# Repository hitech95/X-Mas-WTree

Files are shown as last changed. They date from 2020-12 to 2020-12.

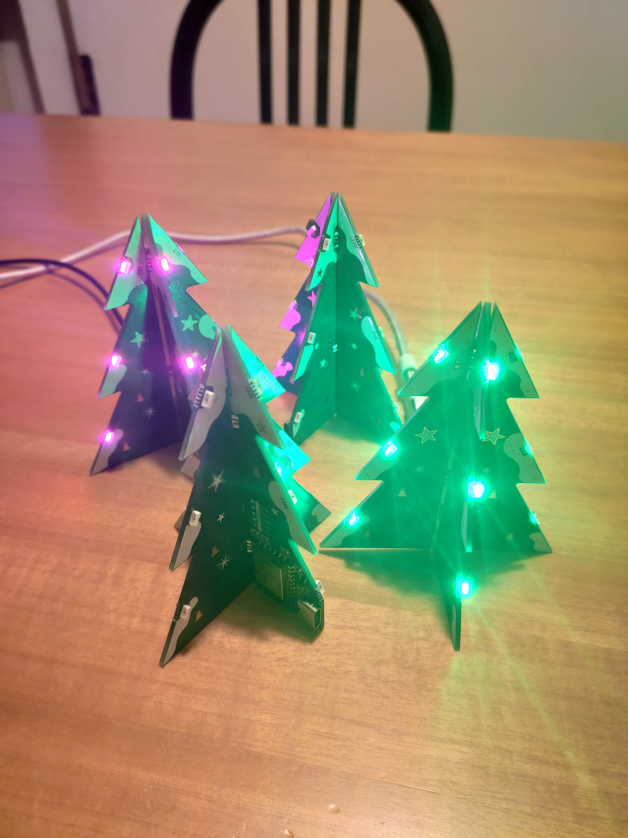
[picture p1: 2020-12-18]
3DModel/IMG_20201218_164741.jpg

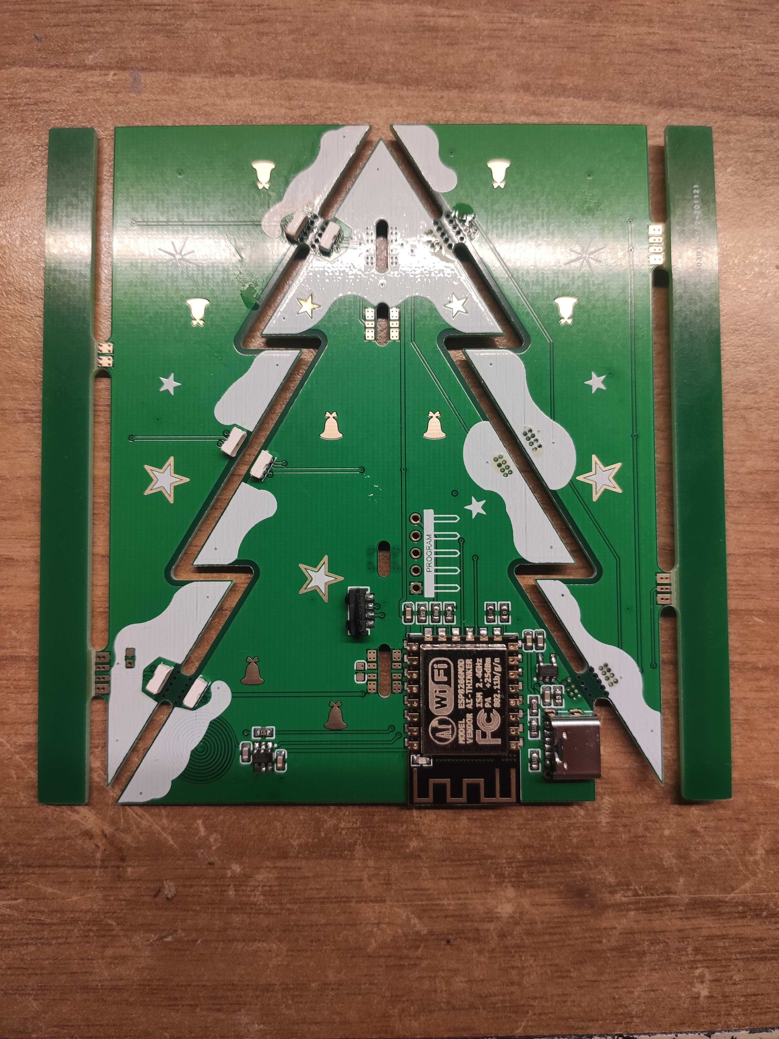
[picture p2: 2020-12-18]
3DModel/IMG_20201217_232000.jpg

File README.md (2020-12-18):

#  X-Mas-WTree!

This is a simple Chrismas tree project inspired by [bluqesh](https://www.instructables.com/PCB-Christms-Tree/). I've updated its design adding slots for board to board connection and addressable RGB leds.

At that point I've also switched the MCU to an ESP8266 to add WiFi capability, and using the amazing [WLED](https://github.com/Aircoookie/WLED) project to control everything.

Project files are available in the `Project Outputs for xMas-Tree` directory.
In the 3DModel folder there is the 3D model and the "textures", and some photos.

### Features

 - USB C Compatible, it negotiate 5V@900mA
 - IR Remote receiver
 - WiFI controllable
 - Full PCB is 10cm x 10cm so it fit the 2$ [JLCPCB](https://jlcpcb.com/) option.
 - Most of the components are available from LCSC.**\***
 - Different patterns and animations
 - More info on [WLED](https://github.com/Aircoookie/WLED) project

**\*The ESP8266-12 and the LEDs have to be bought separately**

## Soldering

While placing the `0603` components is not that hard if you have SMD skills soldering the LEDs is quite **difficult!** Mostly due to the VIAs to give the pads more rigidity. I'm still experimenting a way to easily solder the LEDs, probably using a stencil and low temp solder with hot air is the best solution.

Right now I'm soldering the second tree.

For now my assembly procedure (without hot plate soldering and solder paste) is:

 1. Solder all the `0603` excpet the one near the USB C contacts.
 2. Solder the USB C
 3. Solder the 5.1K resistor skipped on step 1.
 4. Solder the ICs.
 5. Solder the LEDs, make sure that they are firmly soldered.
 6. Solder the ESP module.
 7. Check for shorts and program the ESP. Test if first 6 leds are working.
 8. Snap the boards and solder them together
 9. Check again for shorts and enjoy!

Probably with hot air and a low melting point solder paste step 1-6 can be done in a single jump. 
Right now I only have flux, and 60/40 solder.

I managed to find a old solder paste, and yes, it makes the assemply a lot easier.
I don't have a stencil and in anyu case soldering the LEDs would require manual reworks due to vias under the pads.

To solder the LEDS with this metod i proceed as:
 1. Fill the LED pads with the solder paste proceed with the reflow WITHOUT the LEDs.
 2. The solder would be wiked into the vias, apply again the solder paster and properly reflow the LEDs.
 
With my cheap hot air station I use 360°C to solder all the components and 220°C for the LEDs.

I'm a noob with LED soldering I've melted 8 of them on assempling 4 tree. So be careful.
(Four on the first board, one fell on the fold and was lost. One had RED color not working. The others 2 has been melted on second and third board)

## PCB Errors
 - The USB FUSE seems to be not working as expected, so a 0OHM link is
   required. (This seems to be a single case)
 - The LEDS PADs have vias to give them more strength, but unfortunatly makes a lot harder to solder the LEDs
 - Some 4.7uF caps (LEDs bypass seems to be not needed and some of those cant be soldered or the boards cannot be assempled in shape)

## PROGRAMMING

The touch button is connected to the `BOOT0` pin, so you have to press that while you start the sketch upload process.
A FTDI 3.3V module with `RESET` is required, I didnt had one so I temporary connected a wire to ground while also pressing the TOUCH button.

The FW can be found under the [WLED](https://github.com/Aircoookie/WLED/releases) repository, I'm using a ESP12, so `d1_mini` is the right platform to choose.

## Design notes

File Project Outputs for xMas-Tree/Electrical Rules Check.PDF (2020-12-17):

### Electrical Rules Check Report

Class | Document | Message
Warning | Main.SchDoc | Net LEDS_L has no driving source (Pin LED1-1,Pin R8-2)
Warning | Main.SchDoc | Net TOCUH_PAD has no driving source (Pin C5-2,Pin U3-3)
venerdì 20 nov 2020 3:37:14 PM | Page 1 of 1

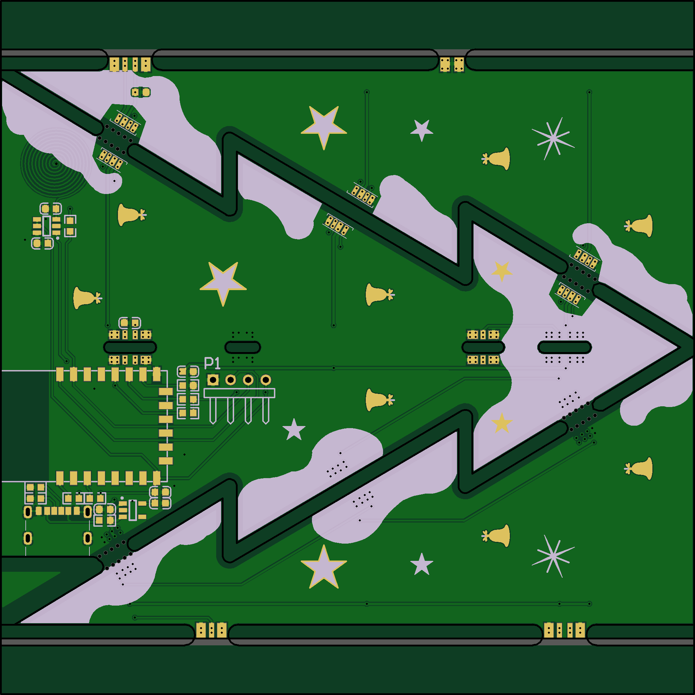
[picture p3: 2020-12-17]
3DModel/top.png

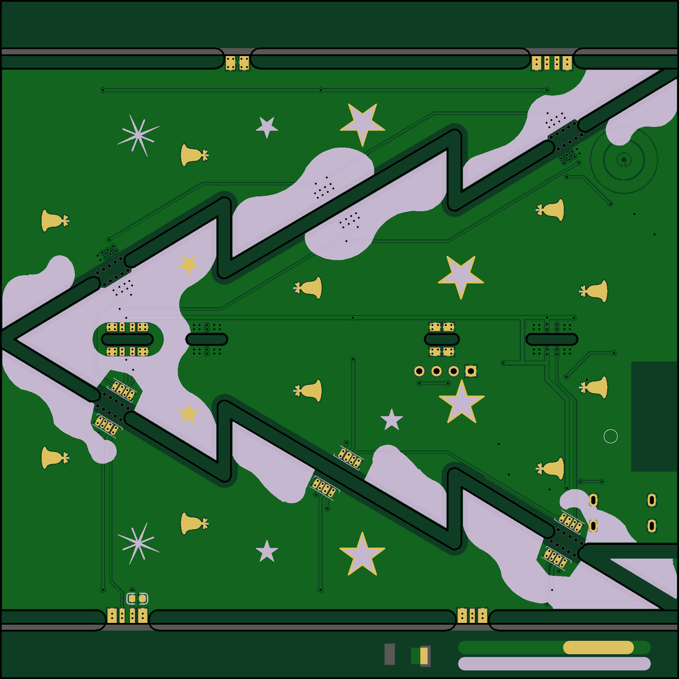
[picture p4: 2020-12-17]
3DModel/bottom.png

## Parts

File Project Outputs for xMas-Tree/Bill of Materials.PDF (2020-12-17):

Comment | Description | Designator | Quantity | Supplier | SuppliersPartNum ber | Manufacturer | PartNumber
10uF | Chip capacitors | C1, C2 | 2 | LC | C19702 | Samsung Electro-Mechanics | CL10A106KP8NN NC
100nF | Chip capacitors | C3, C4 | 2 | LC | C14663 | YAGEO | CC0603KRX7R9B B104
30pF | Chip capacitors | C5 | 1 | LC | C22397 | Samsung Electro-Mechanics | CL10C300JB8NNN C
4.7uF | Chip capacitors | C6, C7, C8, C9 | 4 | LC | C19666 | Samsung Electro-Mechanics | CL10A475KO8NN NC
JK-SMD0603-035 | PTC Resettable Fuse | F1 | 1 | LC | C369144 | Jinrui Electronic Materials Co. | JK-SMD0603-035
SK68XX SIDE | Addressable LED | LED1, LED2, LED3, LED4, LED5, LED6, LED7, LED8, LED9, LED10, LED11, LED12 | 12 | | | Shenzhen Normand Electronic Co.,Ltd | SK6812 SIDE
Header 5H | Header, 5-Pin, Right Angle | P1 | 1
5.1KΩ ±1% | Chip resistor | R1, R2 | 2 | LC | C23186 | Uniroyal Elec | 0603WAF5101T5 E
10KΩ ±1% | Chip resistor | R3, R4, R6, R7 | 4 | LC | C25804 | Uniroyal Elec | 0603WAF1002T5 E
4.7KΩ ±1% | Chip resistor | R5, R8 | 2 | LC | C23162 | Uniroyal Elec | 0603WAF4701T5 E
0Ω ±1% | Chip resistor | R9 | 1 | LC | C21189 | Uniroyal Elec | 0603WAF0000T5 E
ME6211C33 | LDO | U1 | 1 | LC | C82942 | MICRONE(Nanjin g Micro One Elec) | ME6211C33M5G-N
ESP8266-12 | | U2 | 1
TTP223 | Touch Pad Detector IC | U3 | 1 | LC | C93723 | Tontek Design Tech | TTP223N-HA6
SIRAB39R1 | Infrared remote receiver | U4 | 1 | LC | C393728 | Hangzhou Silan Microelectronics | SIRAB39R1
TYPE-C-31-M-17 | USB Connectors | USBC | 1 | LC | C283540 | Korean Hroparts Elec | TYPE-C-31-M-17

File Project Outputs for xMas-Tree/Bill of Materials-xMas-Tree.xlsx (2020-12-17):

Comment | Description | Designator | Quantity | Supplier | SuppliersPartNumber | Manufacturer | PartNumber
10uF | Chip capacitors | C1, C2 | 2 | LC | C19702 | Samsung Electro-Mechanics | CL10A106KP8NNNC
100nF | Chip capacitors | C3, C4 | 2 | LC | C14663 | YAGEO | CC0603KRX7R9BB104
30pF | Chip capacitors | C5 | 1 | LC | C22397 | Samsung Electro-Mechanics | CL10C300JB8NNNC
4.7uF | Chip capacitors | C6, C7, C8, C9 | 4 | LC | C19666 | Samsung Electro-Mechanics | CL10A475KO8NNNC
JK-SMD0603-035 | PTC Resettable Fuse | F1 | 1 | LC | C369144 | Jinrui Electronic Materials Co. | JK-SMD0603-035
SK68XX SIDE | Addressable LED | LED1, LED2, LED3, LED4, LED5, LED6, LED7, LED8, LED9, LED10, LED11, LED12 | 12 |  |  | Shenzhen Normand Electronic Co.,Ltd | SK6812 SIDE
Header 5H | Header, 5-Pin, Right Angle | P1 | 1
5.1KΩ ±1% | Chip resistor | R1, R2 | 2 | LC | C23186 | Uniroyal Elec | 0603WAF5101T5E
10KΩ ±1% | Chip resistor | R3, R4, R6, R7 | 4 | LC | C25804 | Uniroyal Elec | 0603WAF1002T5E
4.7KΩ ±1% | Chip resistor | R5, R8 | 2 | LC | C23162 | Uniroyal Elec | 0603WAF4701T5E
0Ω ±1% | Chip resistor | R9 | 1 | LC | C21189 | Uniroyal Elec | 0603WAF0000T5E
ME6211C33 | LDO | U1 | 1 | LC | C82942 | MICRONE(Nanjing Micro One Elec) | ME6211C33M5G-N
ESP8266-12 |  | U2 | 1
TTP223 | Touch Pad Detector IC | U3 | 1 | LC | C93723 | Tontek Design Tech | TTP223N-HA6
SIRAB39R1 | Infrared remote receiver | U4 | 1 | LC | C393728 | Hangzhou Silan Microelectronics | SIRAB39R1
TYPE-C-31-M-17 | USB Connectors | USBC | 1 | LC | C283540 | Korean Hroparts Elec | TYPE-C-31-M-17

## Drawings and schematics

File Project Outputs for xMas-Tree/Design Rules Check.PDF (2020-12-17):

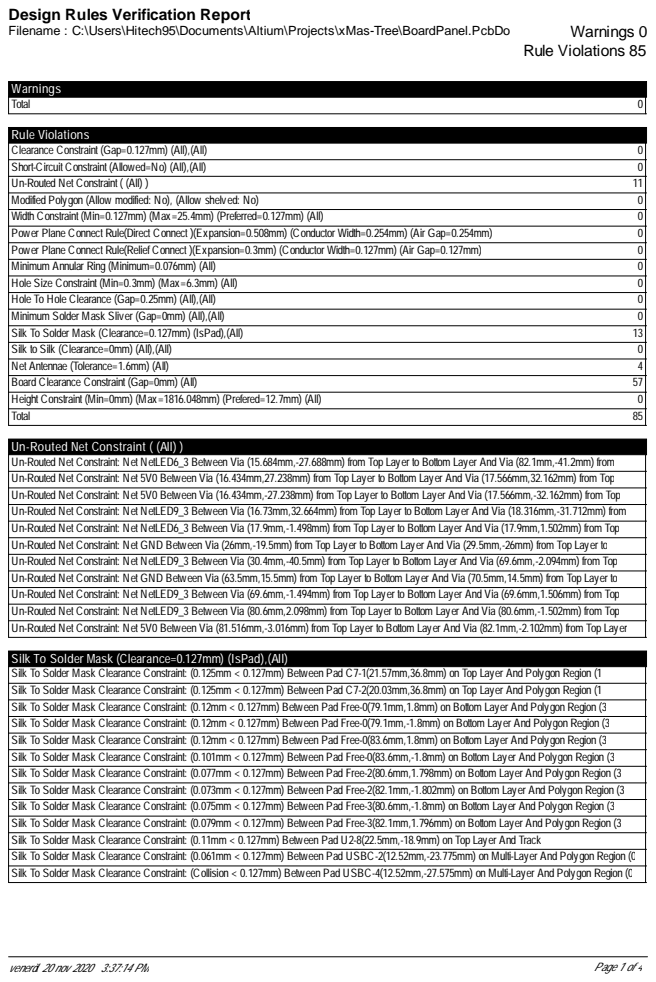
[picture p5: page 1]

Design Rules Verification Report

Un-Routed Net Constraint ( (All) )
Un-Routed Net Constraint: Net NetLED6_3 Between Via (15.684mm,-27.688mm) from Top Layer to Bottom Layer And Via (82.1mm,-41.2mm) from
Un-Routed Net Constraint: Net 5V0 Between Via (16.434mm,27.238mm) from Top Layer to Bottom Layer And Via (17.566mm,32.162mm) from Top
Un-Routed Net Constraint: Net 5V0 Between Via (16.434mm,-27.238mm) from Top Layer to Bottom Layer And Via (17.566mm,-32.162mm) from Top
Un-Routed Net Constraint: Net NetLED9_3 Between Via (16.73mm,32.664mm) from Top Layer to Bottom Layer And Via (18.316mm,-31.712mm) from
Un-Routed Net Constraint: Net NetLED6_3 Between Via (17.9mm,-1.498mm) from Top Layer to Bottom Layer And Via (17.9mm,1.502mm) from Top
Un-Routed Net Constraint: Net GND Between Via (26mm,-19.5mm) from Top Layer to Bottom Layer And Via (29.5mm,-26mm) from Top Layer to
Un-Routed Net Constraint: Net NetLED9_3 Between Via (30.4mm,-40.5mm) from Top Layer to Bottom Layer And Via (69.6mm,-2.094mm) from Top
Un-Routed Net Constraint: Net GND Between Via (63.5mm,15.5mm) from Top Layer to Bottom Layer And Via (70.5mm,14.5mm) from Top Layer to
Un-Routed Net Constraint: Net NetLED9_3 Between Via (69.6mm,-1.494mm) from Top Layer to Bottom Layer And Via (69.6mm,1.506mm) from Top
Un-Routed Net Constraint: Net NetLED9_3 Between Via (80.6mm,2.098mm) from Top Layer to Bottom Layer And Via (80.6mm,-1.502mm) from Top
Un-Routed Net Constraint: Net 5V0 Between Via (81.516mm,-3.016mm) from Top Layer to Bottom Layer And Via (82.1mm,-2.102mm) from Top Layer

Silk To Solder Mask (Clearance=0.127mm) (IsPad),(All)
Silk To Solder Mask Clearance Constraint: (0.125mm < 0.127mm) Between Pad C7-1(21.57mm,36.8mm) on Top Layer And Polygon Region (1
Silk To Solder Mask Clearance Constraint: (0.125mm < 0.127mm) Between Pad C7-2(20.03mm,36.8mm) on Top Layer And Polygon Region (1
Silk To Solder Mask Clearance Constraint: (0.12mm < 0.127mm) Between Pad Free-0(79.1mm,1.8mm) on Bottom Layer And Polygon Region (3
Silk To Solder Mask Clearance Constraint: (0.12mm < 0.127mm) Between Pad Free-0(79.1mm,-1.8mm) on Bottom Layer And Polygon Region (3
Silk To Solder Mask Clearance Constraint: (0.12mm < 0.127mm) Between Pad Free-0(83.6mm,1.8mm) on Bottom Layer And Polygon Region (3
Silk To Solder Mask Clearance Constraint: (0.101mm < 0.127mm) Between Pad Free-0(83.6mm,-1.8mm) on Bottom Layer And Polygon Region (3
Silk To Solder Mask Clearance Constraint: (0.077mm < 0.127mm) Between Pad Free-2(80.6mm,1.798mm) on Bottom Layer And Polygon Region (3
Silk To Solder Mask Clearance Constraint: (0.073mm < 0.127mm) Between Pad Free-2(82.1mm,-1.802mm) on Bottom Layer And Polygon Region (3
Silk To Solder Mask Clearance Constraint: (0.075mm < 0.127mm) Between Pad Free-3(80.6mm,-1.8mm) on Bottom Layer And Polygon Region (3
Silk To Solder Mask Clearance Constraint: (0.079mm < 0.127mm) Between Pad Free-3(82.1mm,1.796mm) on Bottom Layer And Polygon Region (3
Silk To Solder Mask Clearance Constraint: (0.11mm < 0.127mm) Between Pad U2-8(22.5mm,-18.9mm) on Top Layer And Track
Silk To Solder Mask Clearance Constraint: (0.061mm < 0.127mm) Between Pad USBC-2(12.52mm,-23.775mm) on Multi-Layer And Polygon Region (0
Silk To Solder Mask Clearance Constraint: (Collision < 0.127mm) Between Pad USBC-4(12.52mm,-27.575mm) on Multi-Layer And Polygon Region (0

Net Antennae (Tolerance=1.6mm) (All)
Net Antennae: Via (80.6mm,-1.502mm) from Top Layer to Bottom Layer Net Antennae: Via (80.6mm,-2.102mm) from Top Layer to Bottom Layer Net Antennae: Via (82.1mm,-1.502mm) from Top Layer to Bottom Layer Net Antennae: Via (82.1mm,-2.102mm) from Top Layer to Bottom Layer

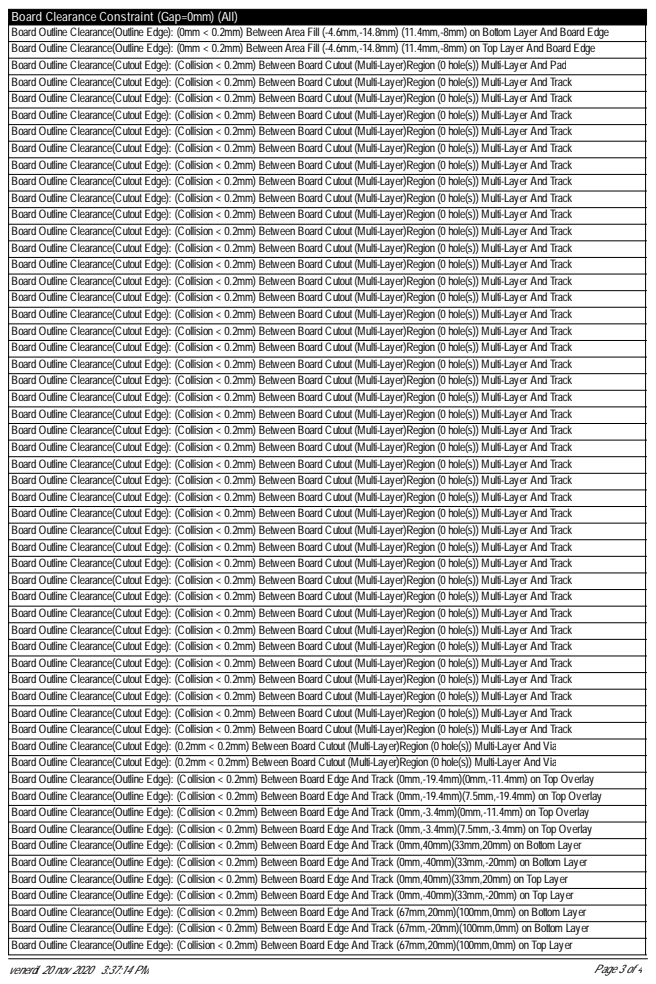
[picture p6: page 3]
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

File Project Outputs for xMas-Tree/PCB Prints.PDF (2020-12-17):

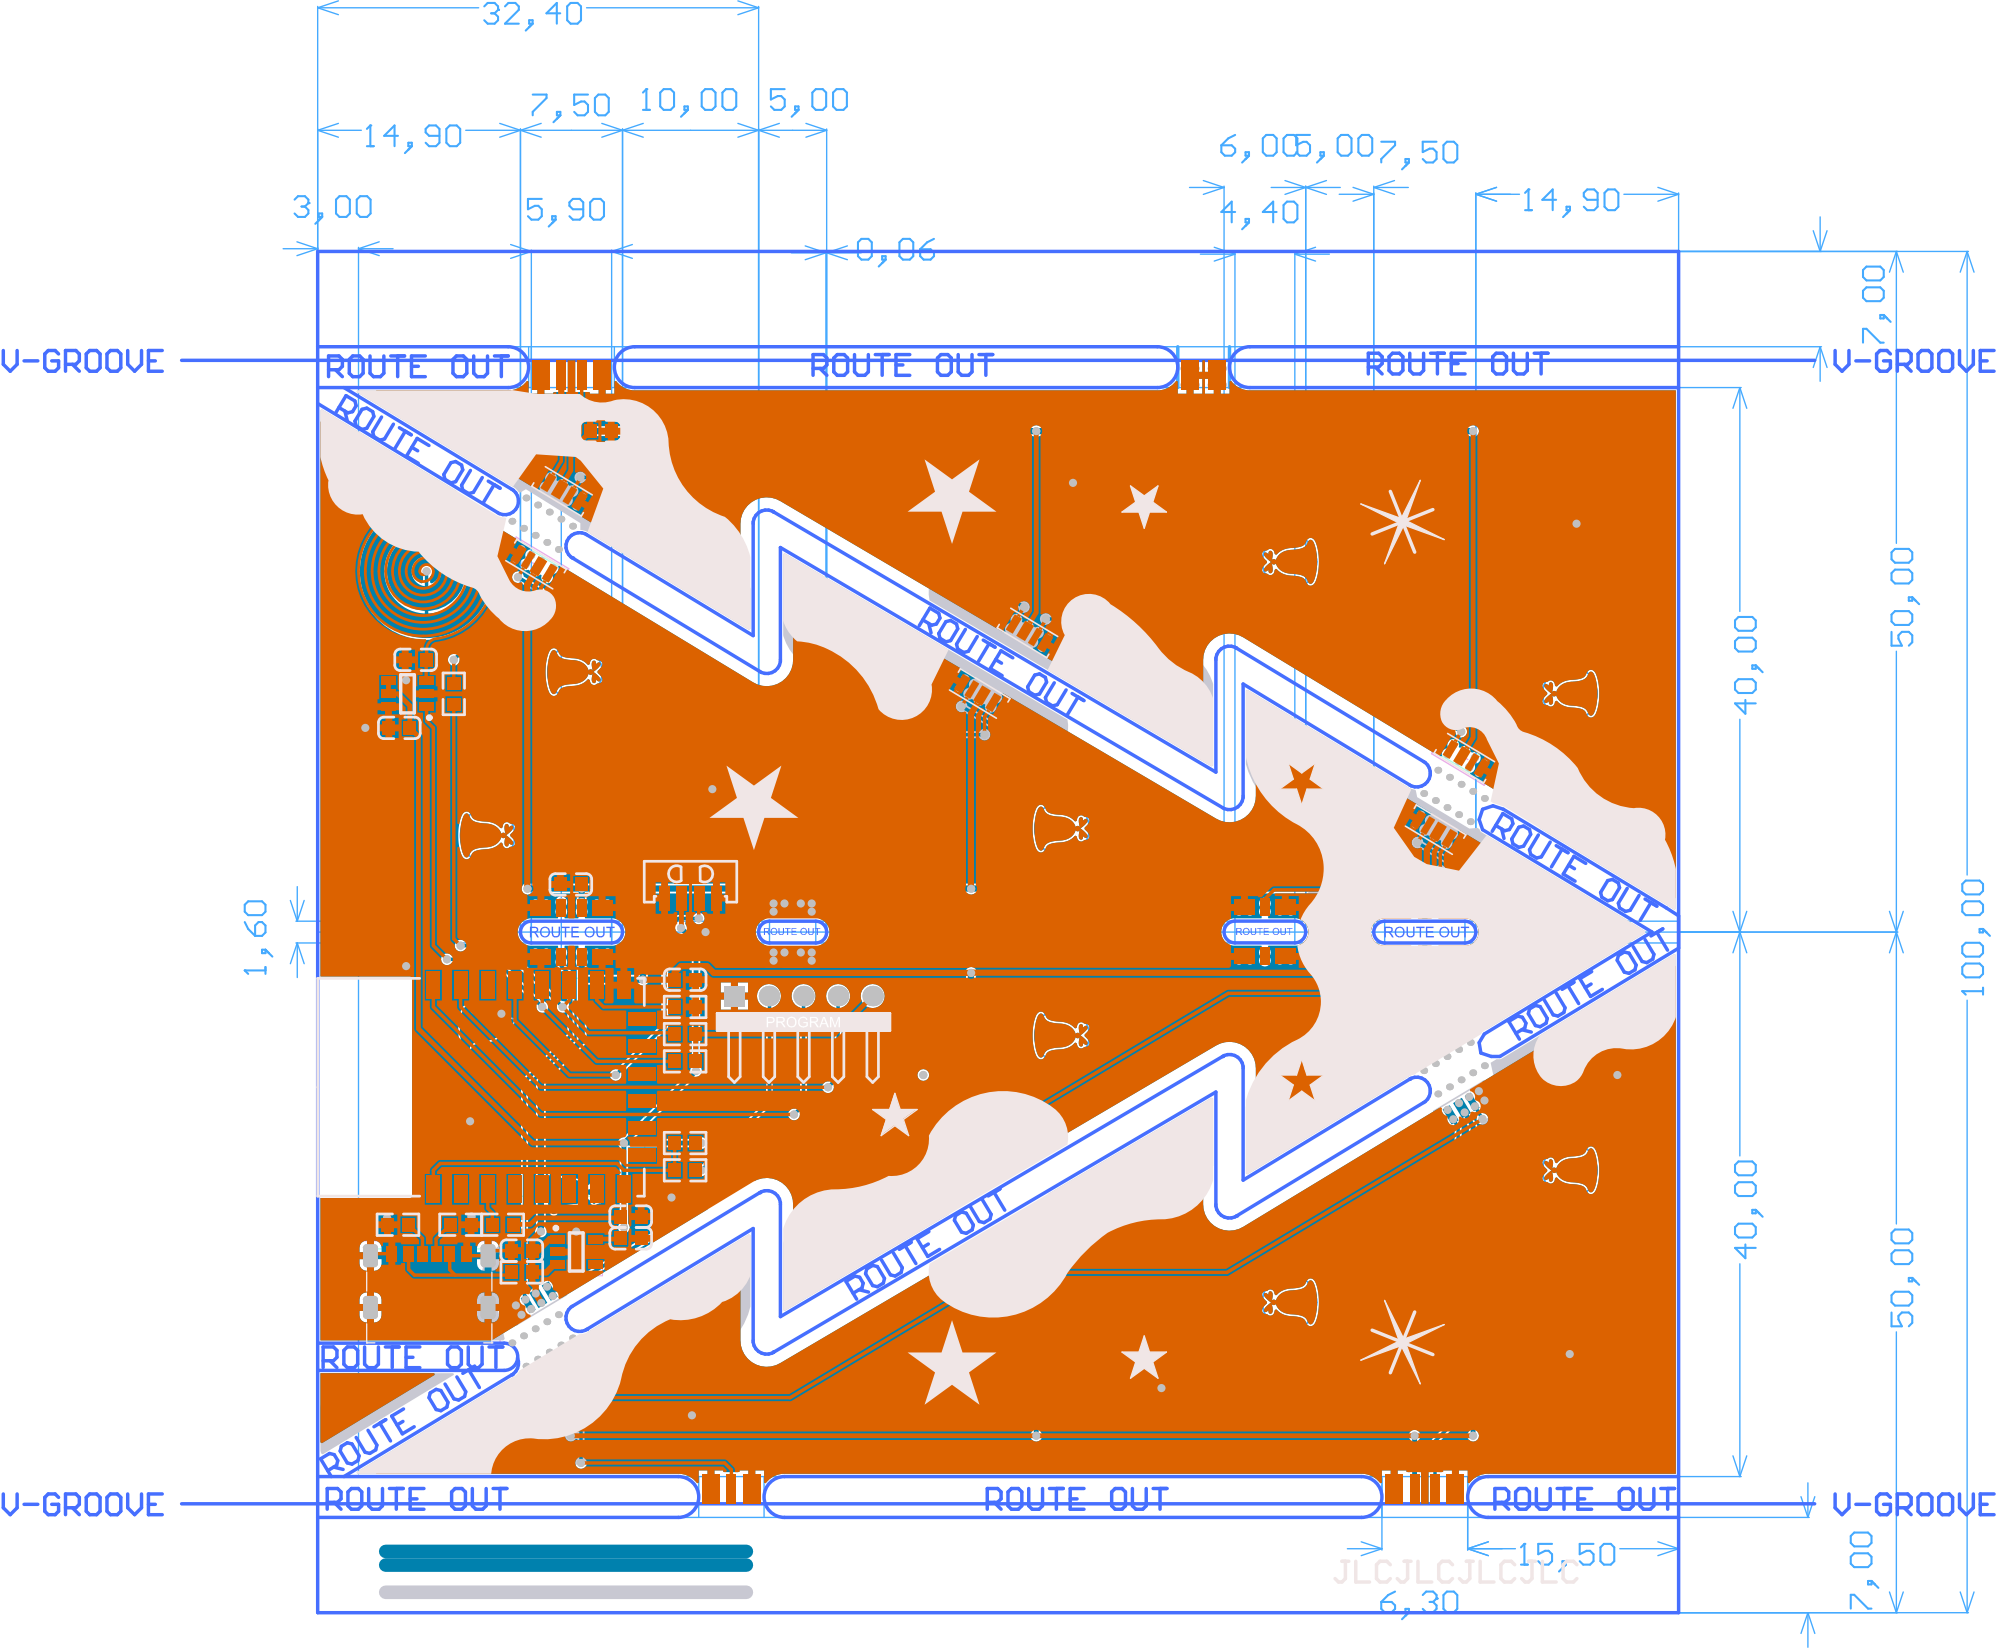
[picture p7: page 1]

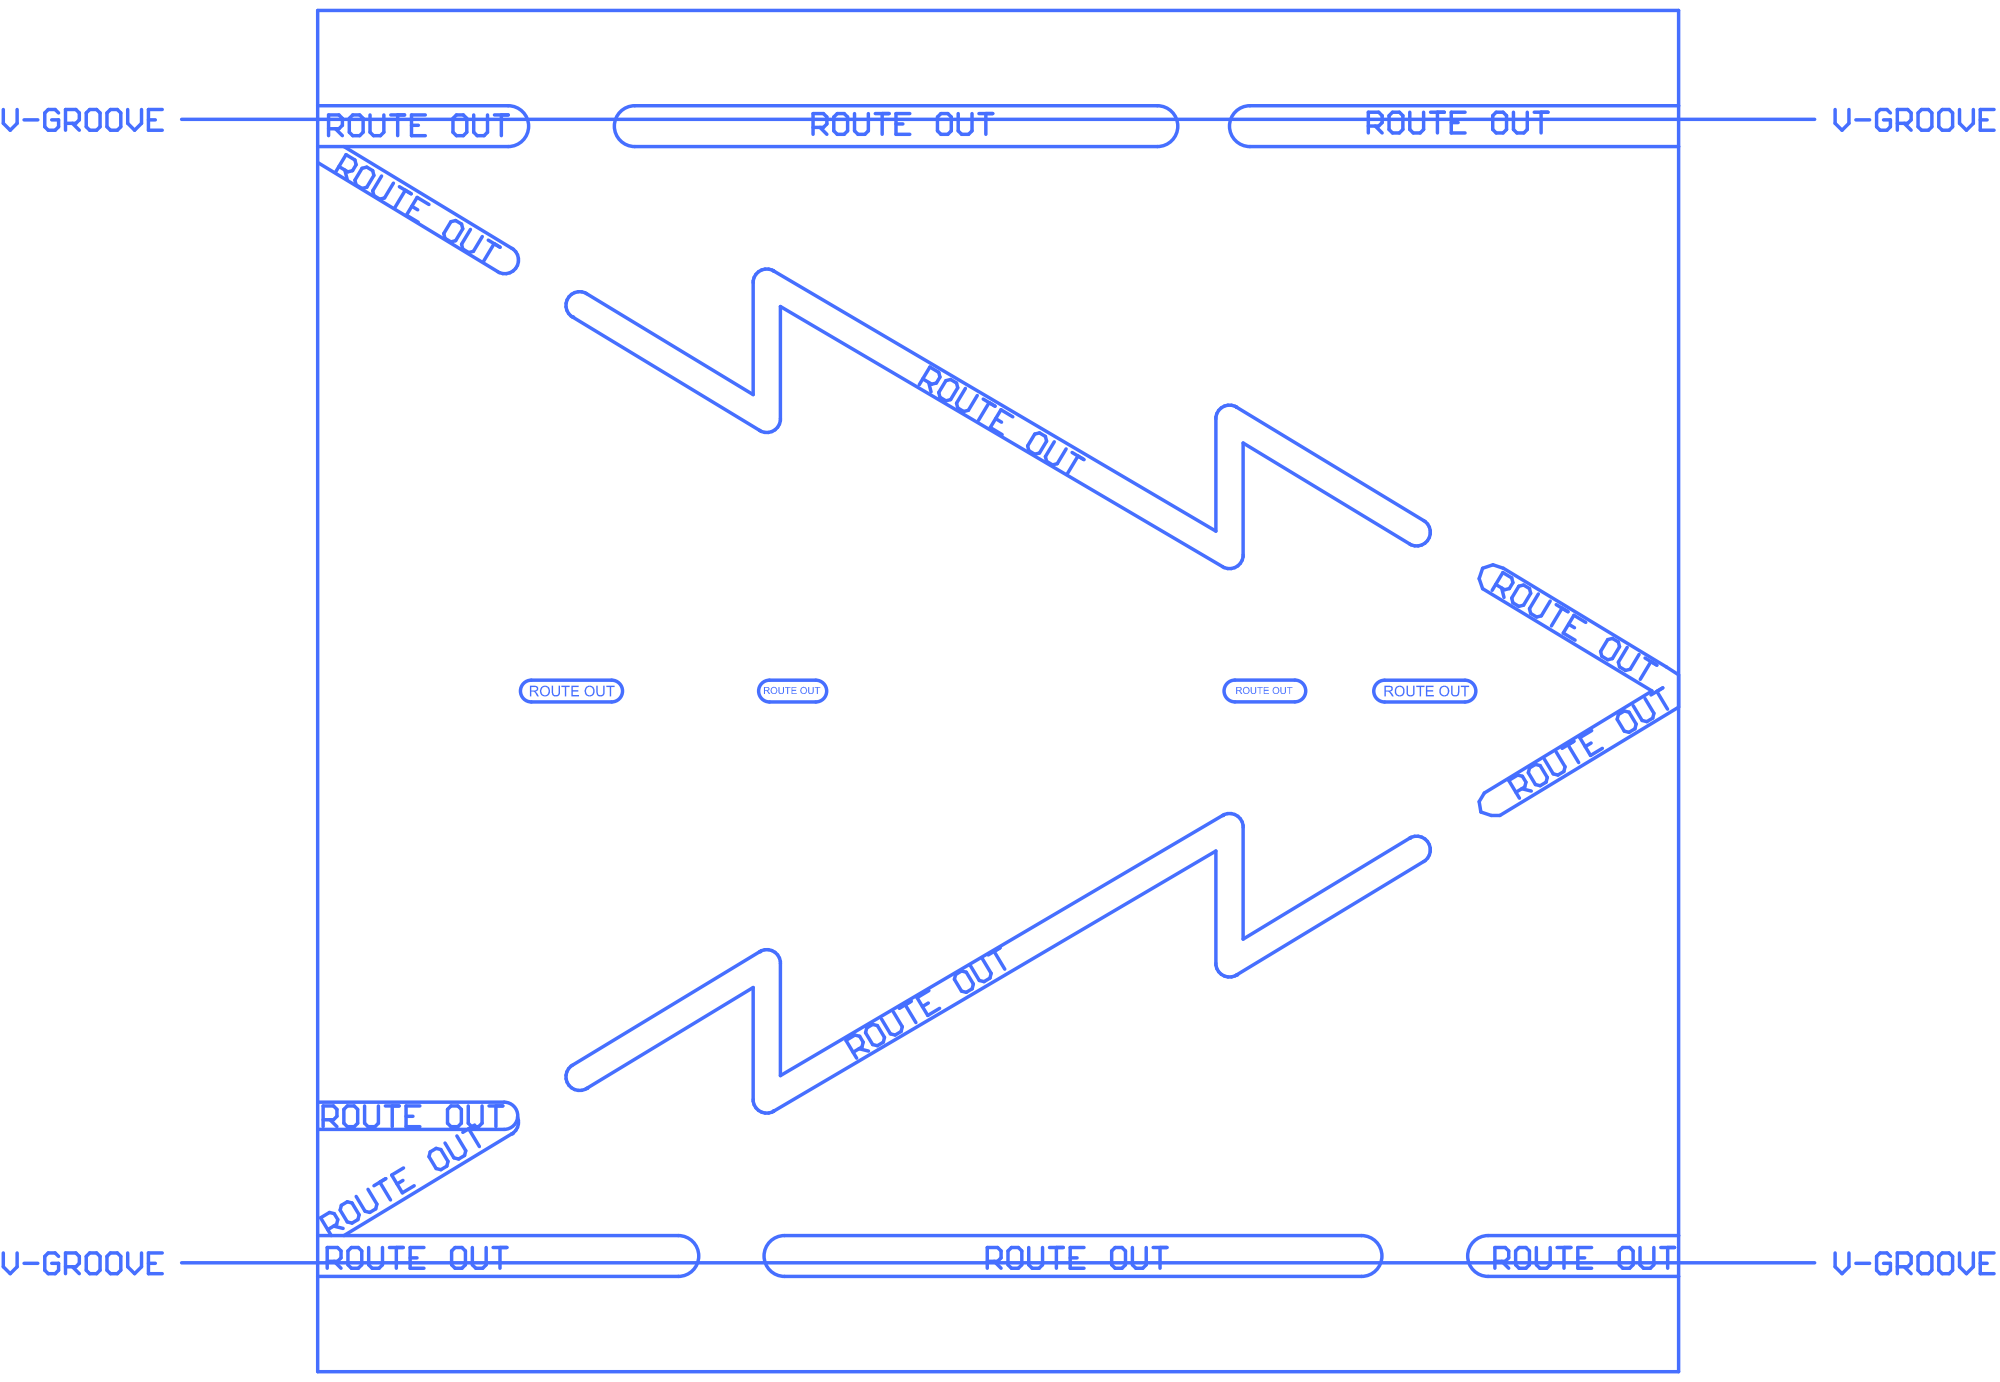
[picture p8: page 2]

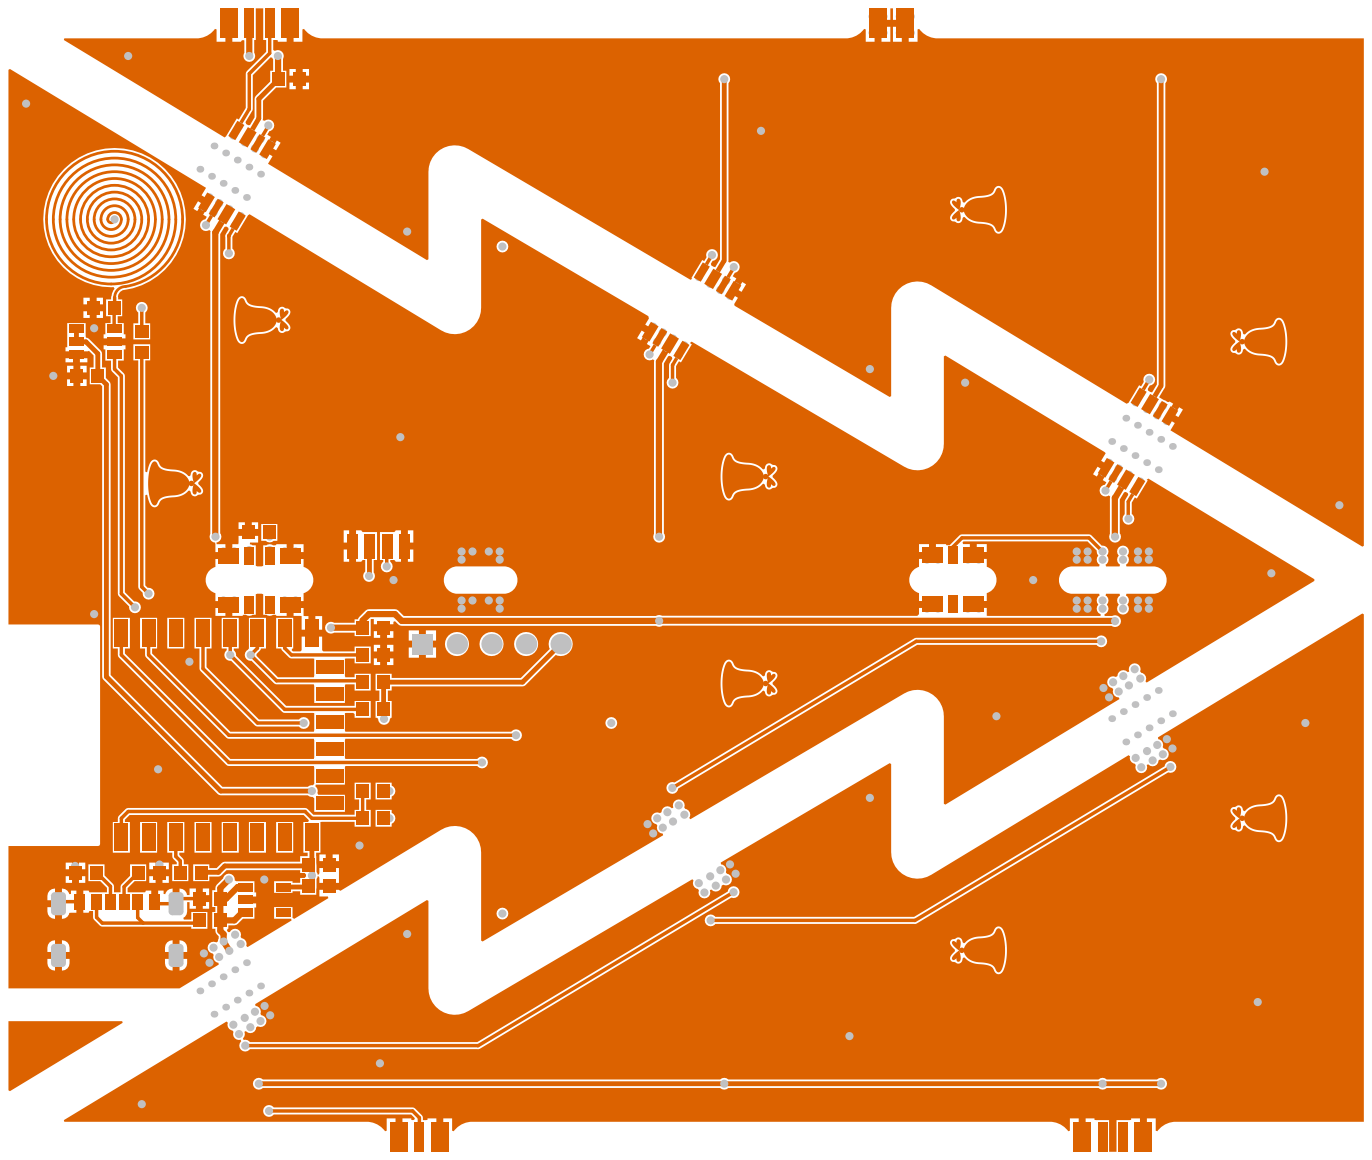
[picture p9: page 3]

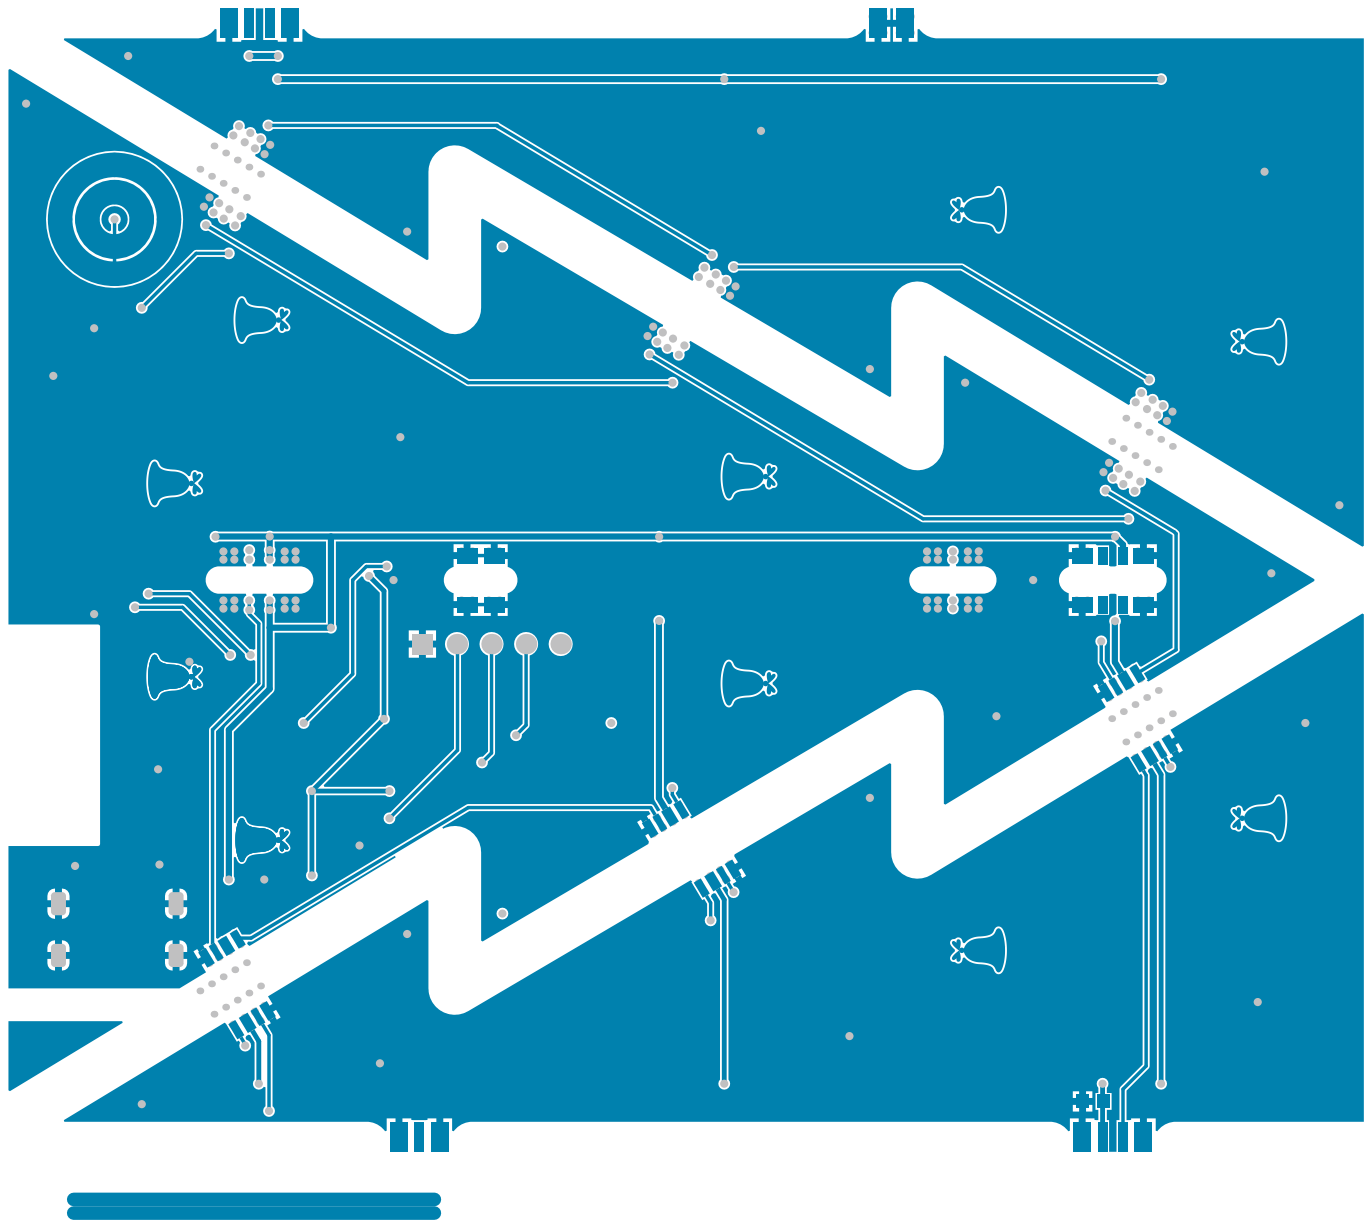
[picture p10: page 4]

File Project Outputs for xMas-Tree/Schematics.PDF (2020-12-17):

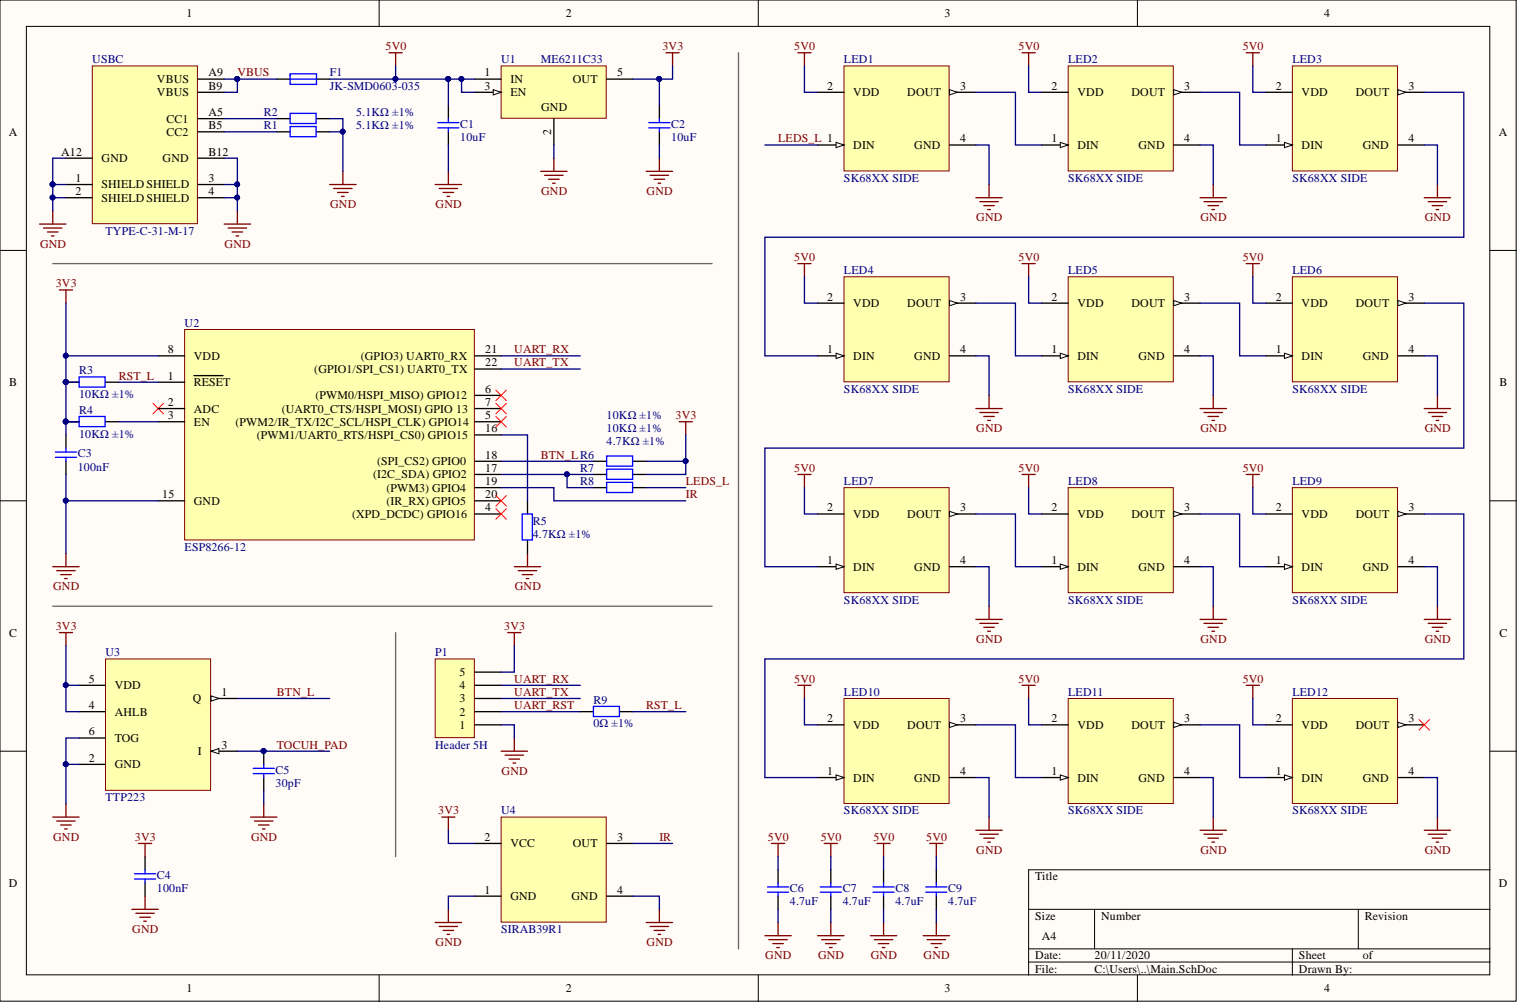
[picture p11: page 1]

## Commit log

2020-12-17 Project upload
    [Bill of Materials-xMas-Tree.xlsx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]
2020-12-18 Update Readme - Added more info on reflow soldering
2020-12-18 Readme add LED melting issues
